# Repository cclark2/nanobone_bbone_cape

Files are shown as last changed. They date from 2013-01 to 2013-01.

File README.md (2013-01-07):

NanoBone BeagleBone Cape
========================

A cape connecting all BeagleBone P8/P9 I/Os to the pins of the $89 DE0-Nano FPGA board. Use it to add an FPGA to your BeagleBone project!

Special thanks to <a href="http://www.sparkfun.com/">SparkFun</a> for use of their open-source EAGLE libraries.

## Project Links
- <a href="http://www.hitchhikeree.org/beaglebone_capes/nanobone/">HitchhikerEE page</a>
- <a href="http://www.youtube.com/watch?v=jys_sxTUOd8">YouTube video</a>
- <a href="https://docs.google.com/folder/d/0B5HjtPsFD8u5YW9CNGdPOElQOEU/edit">Design files on Google Drive</a>
- <a href="http://beagleboard.org/CapeContest/entries/NanoBone/">BeagleBone Cape Contest page</a>

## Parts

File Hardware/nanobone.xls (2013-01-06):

Qty | Value | Device | Package | Parts | Description | MF | MPN | Price | Total
1 |  | CAT24C256 | SOIC8 | U$1 |  |  | CAT24C256WI-GT3 | $0.65 | $0.65
2 |  | FE20-2 | FE20-2 | SV1, SV2 | FEMALE HEADER |  | NPPC202KFMS-RC | 3.9 | 7.8
2 |  | FE23-2_SMD | FE23-2_SMD | P8, P9 | FEMALE HEADER |  | NPPC232KFMS-RC | 3.54 | 7.08
4 |  | HOLE | HOLE | H1, H2, H3, H4 |  |  |  |  | 0
1 |  | M02LOCK_LONGPADS | 1X02_LOCK_LONGPADS | JP1 | Header 2 |  |  |  | 0
1 |  | MA03-1 | MA03-1 | SV3 | PIN HEADER |  |  |  | 0
1 | 0.1u | C-EUC0603 | C0603 | C1 | CAPACITOR, European symbol |  | VJ0603V104ZXXCW1BC | 0.06 | 0.06
1 | 10K | R-US_R0603 | R0603 | R9 | RESISTOR, American symbol |  | WR06X1002FTL | 0.02 | 0.02
1 | 150 | R-US_R0603 | R0603 | R6 | RESISTOR, American symbol |  | 302-150-RC | 0.04 | 0.04
1 | 219-02 | 219-02 | CTS-219-02 | S1 | Surface Mount DIP Switch Series 219 SMT |  | 219-2MST | 0.58 | 0.58
3 | 4.75K | R-US_R0603 | R0603 | R2, R5, R7 | RESISTOR, American symbol |  | CR0603-FX-4751GLF | 0.04 | 0.12
1 | 4.75K, DNI | R-US_R0603 | R0603 | R4 | RESISTOR, American symbol |  | CR0603-FX-4751GLF | 0.04 | 0.04
2 | 5.6K, 5% | R-US_R0603 | R0603 | R1, R3 | RESISTOR, American symbol |  | RK73B1JTTDD562J | 0.06 | 0.12
1 | 50 | R-US_R0603 | R0603 | R8 | RESISTOR, American symbol |  | 302-49.9-RC | 0.04 | 0.04
1 | TPB2,54 | TPB2,54 | B2,54 | TP1 | Test pad |  |  |  | 0
1 | blue | LEDCHIPLED_0603 | CHIPLED_0603 | LED1 | LED |  | HT-193NB-5589 | 0.15 | 0.15
1 | green | LEDCHIPLED_0603 | CHIPLED_0603 | LED2 | LED |  | LG Q971-KN-1 | 0.1 | 0.1
 |  |  |  |  |  |  |  |  | $16.80
 |  |  |  |  |  |  | Need an $86.25 DE0-Nano board from DigiKey
 |  |  |  |  |  |  | Need male headers to mate cape to BeagleBone

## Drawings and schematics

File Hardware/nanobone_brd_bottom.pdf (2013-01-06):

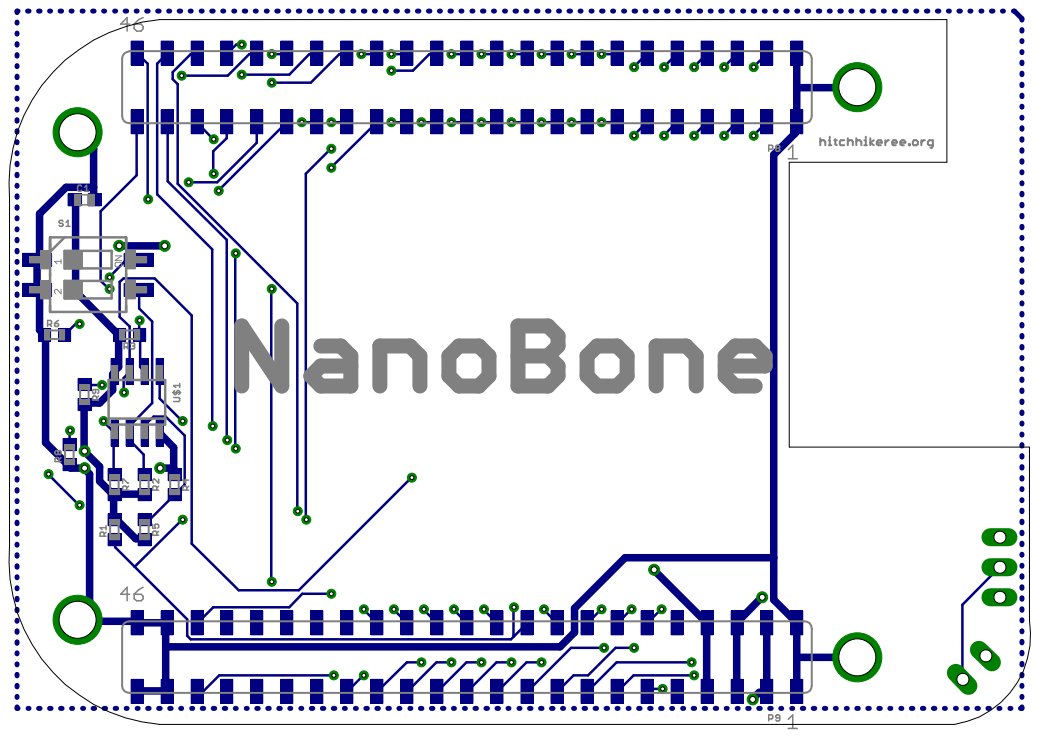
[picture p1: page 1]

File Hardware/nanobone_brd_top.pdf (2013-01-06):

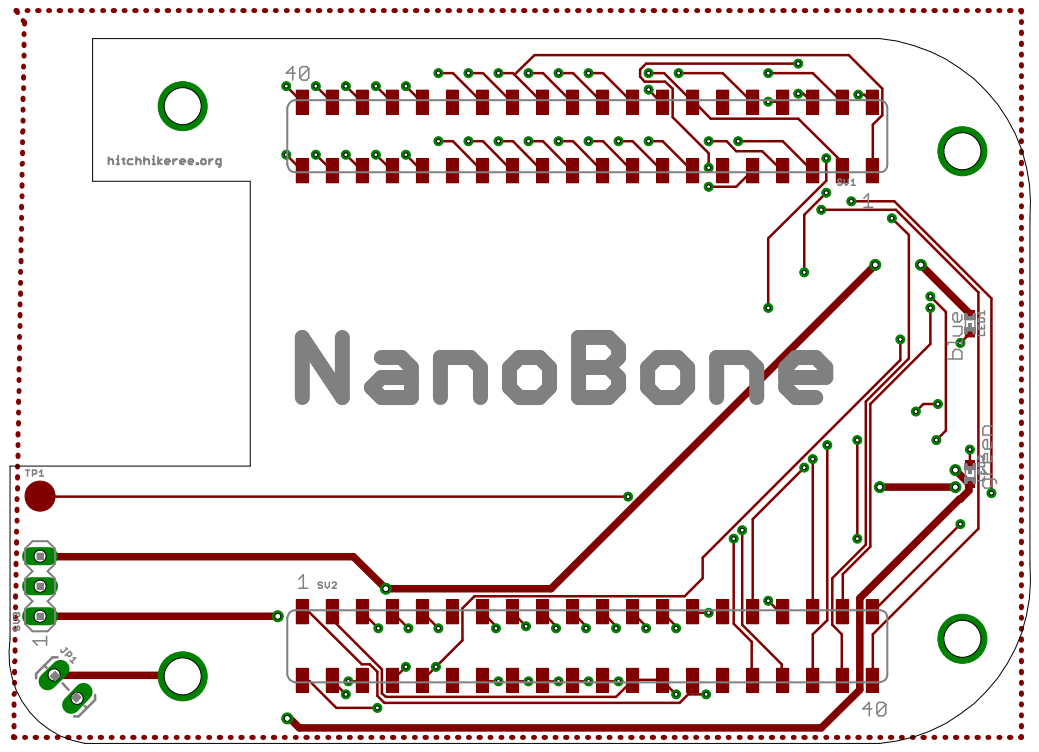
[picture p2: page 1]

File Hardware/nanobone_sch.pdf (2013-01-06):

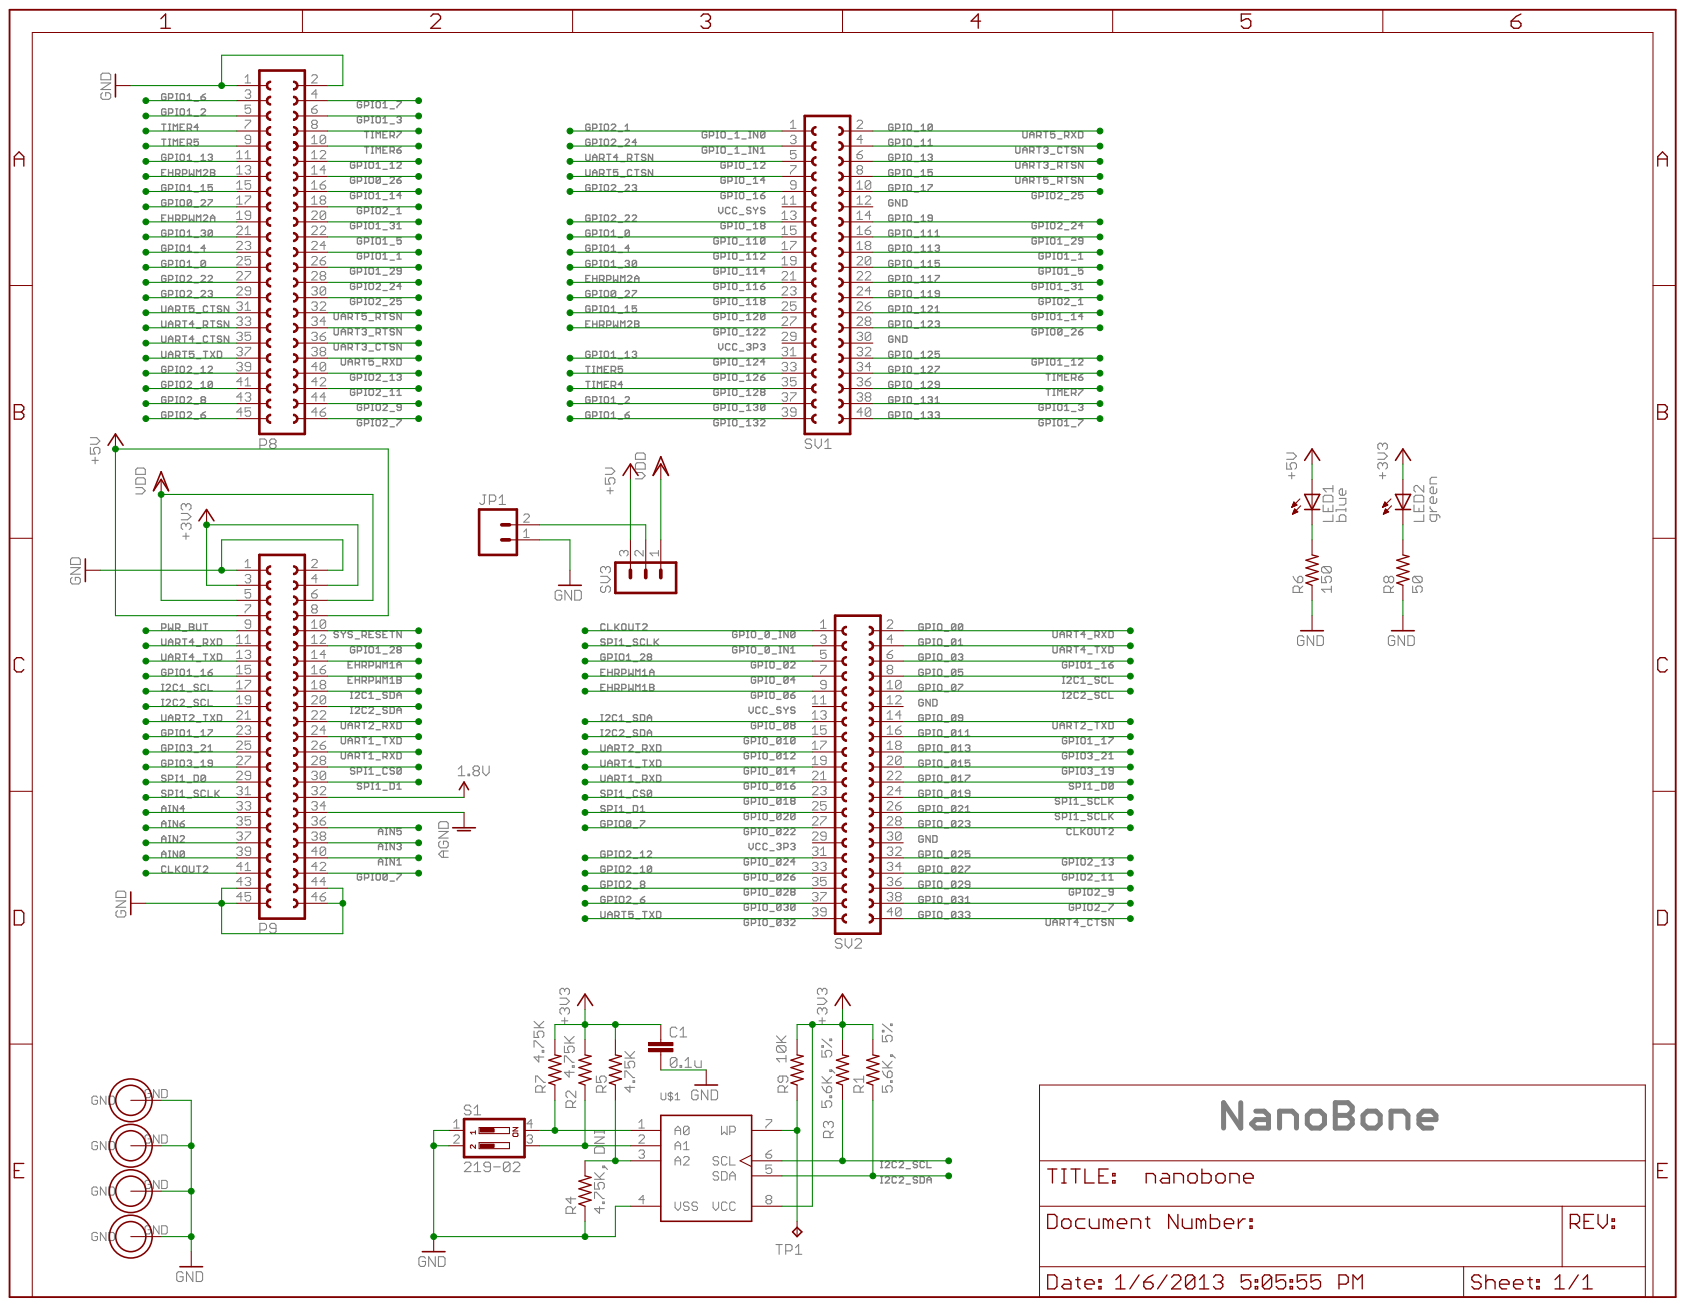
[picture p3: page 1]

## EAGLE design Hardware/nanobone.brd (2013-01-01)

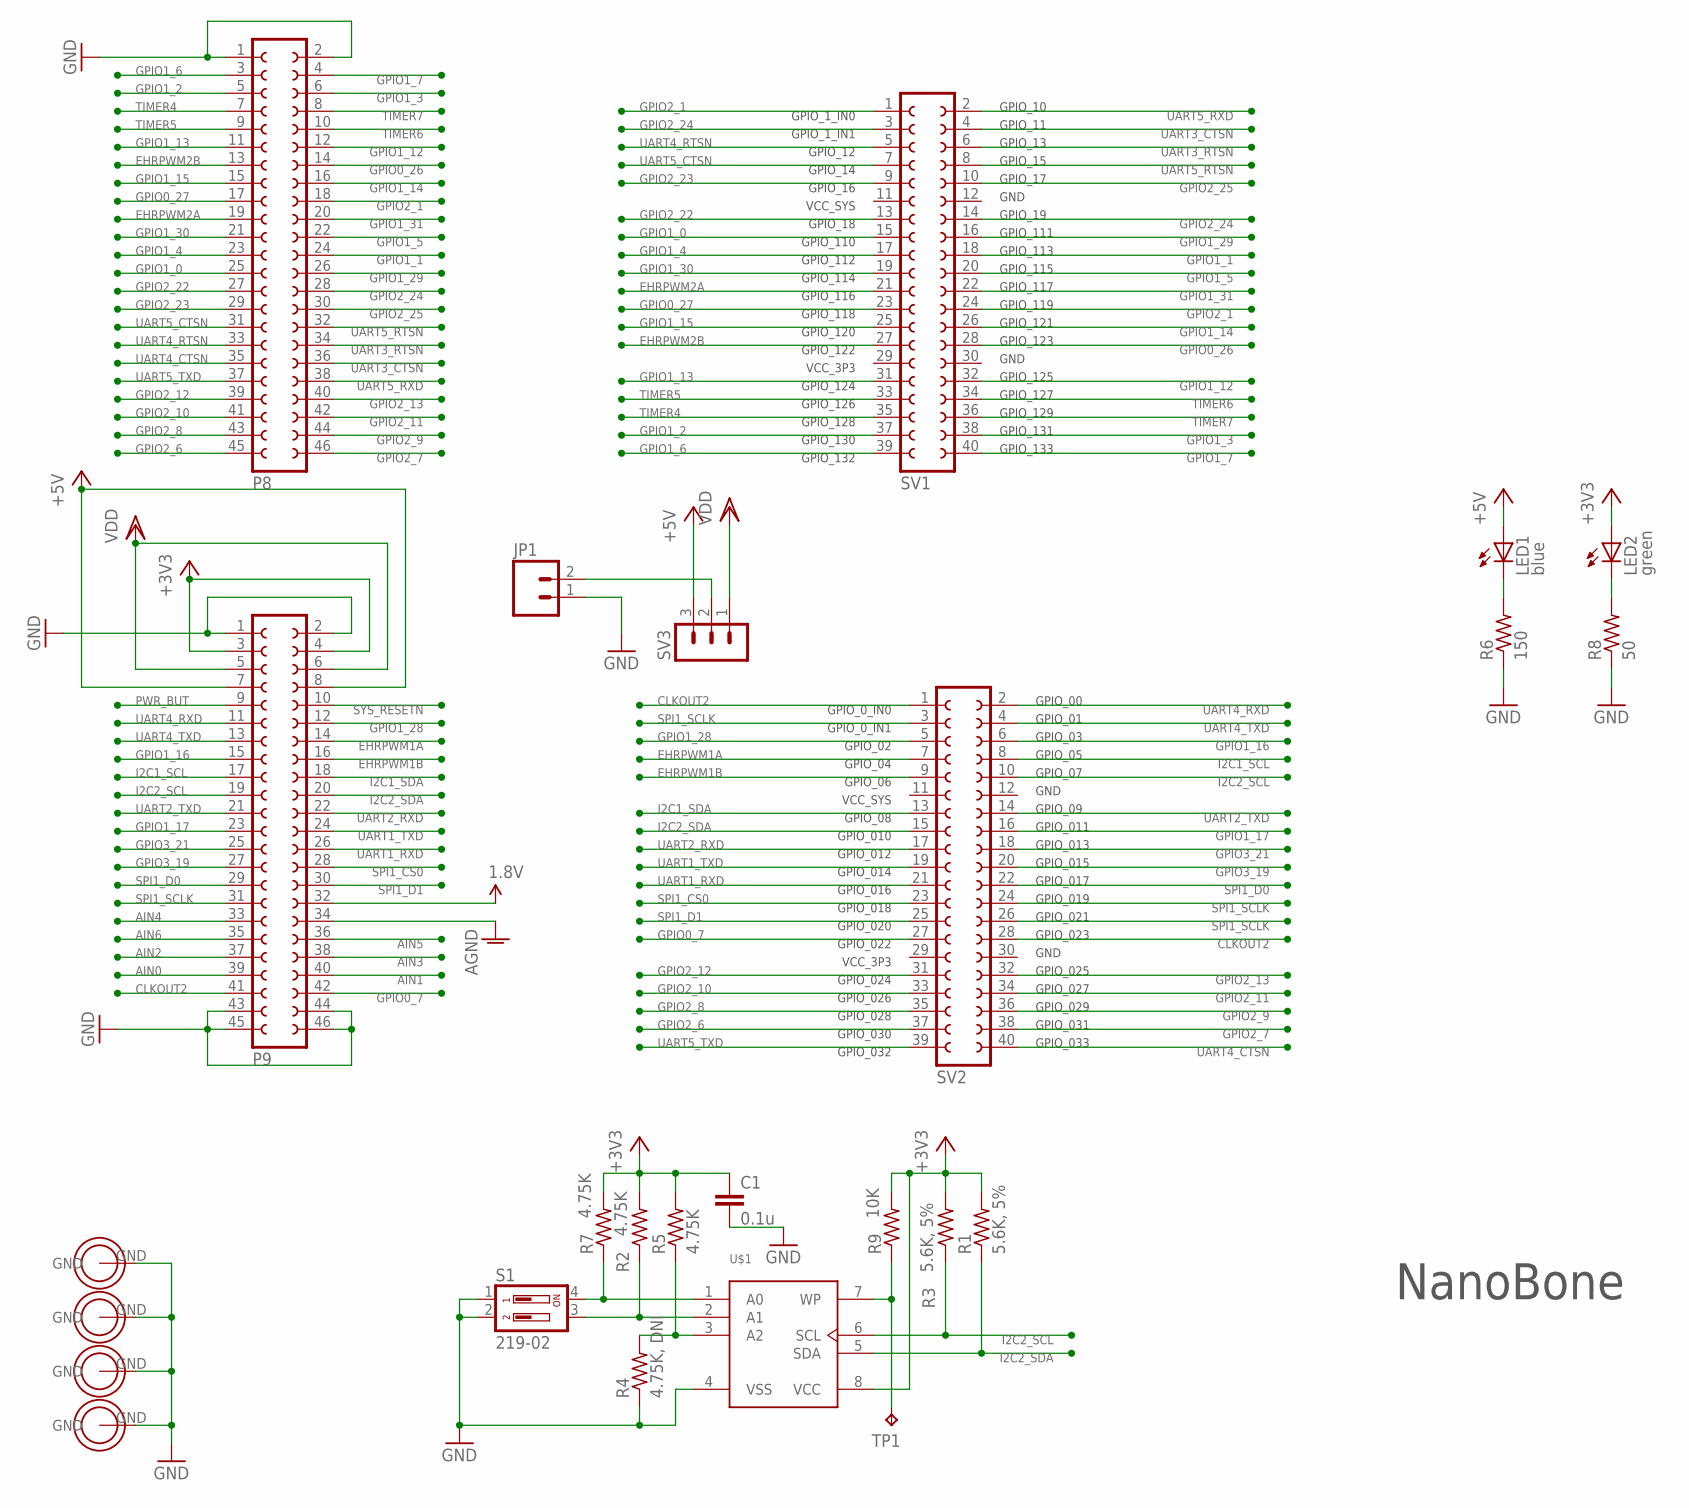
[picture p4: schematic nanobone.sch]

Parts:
C1: 0.1u; C0603; MPN VJ0603V104ZXXCW1BC
H1, H2, H3, H4: HOLE
JP1: M02LOCK_LONGPADS; 1X02_LOCK_LONGPADS
LED1: blue; CHIPLED_0603; MPN HT-193NB-5589
LED2: green; CHIPLED_0603; MPN LG Q971-KN-1
P8, P9: FE23-2_SMD; MPN NPPC232KFMS-RC
R1, R3: 5.6K, 5%; R0603; MPN RK73B1JTTDD562J
R2, R5, R7: 4.75K; R0603; MPN CR0603-FX-4751GLF
R4: 4.75K, DNI; R0603; MPN CR0603-FX-4751GLF
R6: 150; R0603; MPN 302-150-RC
R8: 50; R0603; MPN 302-49.9-RC
R9: 10K; R0603; MPN WR06X1002FTL
S1: 219-02; CTS-219-02; MPN 219-2MST
SV1, SV2: FE20-2; MPN NPPC202KFMS-RC
SV3: MA03-1
TP1: TPB2,54; B2,54
U$1: CAT24C256; SOIC8; MPN CAT24C256WI-GT3

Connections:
1.8V: P9.32
+3V3: C1.1, LED2.A, P9.3, P9.4, R1.2, R2.2, R3.2, R5.2, R7.2, R9.2, U$1.8 (VCC)
+5V: LED1.A, P9.7, P9.8, SV3.3
AGND: P9.34
AIN0: P9.39
AIN1: P9.40
AIN2: P9.37
AIN3: P9.38
AIN4: P9.33
AIN5: P9.36
AIN6: P9.35
CLKOUT2: P9.41, SV2.1, SV2.28
EHRPWM1A: P9.14, SV2.7
EHRPWM1B: P9.16, SV2.9
EHRPWM2A: P8.19, SV1.21
EHRPWM2B: P8.13, SV1.27
GND: C1.2, H1.GND, H2.GND, H3.GND, H4.GND, JP1.1, P8.1, P8.2, P9.1, P9.2, P9.43, P9.44, P9.45, P9.46, R4.1, R6.1, R8.1, S1.1, S1.2, U$1.4 (VSS)
GPIO0_7: P9.42, SV2.27
GPIO0_26: P8.14, SV1.28
GPIO0_27: P8.17, SV1.23
GPIO1_0: P8.25, SV1.15
GPIO1_1: P8.24, SV1.18
GPIO1_2: P8.5, SV1.37
GPIO1_3: P8.6, SV1.38
GPIO1_4: P8.23, SV1.17
GPIO1_5: P8.22, SV1.20
GPIO1_6: P8.3, SV1.39
GPIO1_7: P8.4, SV1.40
GPIO1_12: P8.12, SV1.32
GPIO1_13: P8.11, SV1.31
GPIO1_14: P8.16, SV1.26
GPIO1_15: P8.15, SV1.25
GPIO1_16: P9.15, SV2.6
GPIO1_17: P9.23, SV2.16
GPIO1_28: P9.12, SV2.5
GPIO1_29: P8.26, SV1.16
GPIO1_30: P8.21, SV1.19
GPIO1_31: P8.20, SV1.22
GPIO2_1: P8.18, SV1.1, SV1.24
GPIO2_6: P8.45, SV2.37
GPIO2_7: P8.46, SV2.38
GPIO2_8: P8.43, SV2.35
GPIO2_9: P8.44, SV2.36
GPIO2_10: P8.41, SV2.33
GPIO2_11: P8.42, SV2.34
GPIO2_12: P8.39, SV2.31
GPIO2_13: P8.40, SV2.32
GPIO2_22: P8.27, SV1.13
GPIO2_23: P8.29, SV1.9
GPIO2_24: P8.28, SV1.3, SV1.14
GPIO2_25: P8.30, SV1.10
GPIO3_19: P9.27, SV2.20
GPIO3_21: P9.25, SV2.18
I2C1_SCL: P9.17, SV2.8
I2C1_SDA: P9.18, SV2.13
I2C2_SCL: P9.19, R3.1, SV2.10, U$1.6 (SCL)
I2C2_SDA: P9.20, R1.1, SV2.15, U$1.5 (SDA)
unnamed: R7.1, S1.4, U$1.1 (A0)
unnamed: R2.1, S1.3, U$1.2 (A1)
unnamed: R4.2, R5.1, U$1.3 (A2)
unnamed: JP1.2, SV3.2
unnamed: R9.1, TP1.TP, U$1.7 (WP)
unnamed: LED1.C, R6.2
unnamed: LED2.C, R8.2
PWR_BUT: P9.9
SPI1_CS0: P9.28, SV2.23
SPI1_D0: P9.29, SV2.22
SPI1_D1: P9.30, SV2.25
SPI1_SCLK: P9.31, SV2.3, SV2.24, SV2.26
SYS_RESETN: P9.10
TIMER4: P8.7, SV1.35
TIMER5: P8.9, SV1.33
TIMER6: P8.10, SV1.34
TIMER7: P8.8, SV1.36
UART1_RXD: P9.26, SV2.21
UART1_TXD: P9.24, SV2.19
UART2_RXD: P9.22, SV2.17
UART2_TXD: P9.21, SV2.14
UART3_CTSN: P8.36, SV1.4
UART3_RTSN: P8.34, SV1.6
UART4_CTSN: P8.35, SV2.40
UART4_RTSN: P8.33, SV1.5
UART4_RXD: P9.11, SV2.2
UART4_TXD: P9.13, SV2.4
UART5_CTSN: P8.31, SV1.7
UART5_RTSN: P8.32, SV1.8
UART5_RXD: P8.38, SV1.2
UART5_TXD: P8.37, SV2.39
VDD: P9.5, P9.6, SV3.1

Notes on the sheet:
NanoBone
GPIO_0_IN0
GPIO_00
GPIO_01
GPIO_03
GPIO_05
GPIO_07
GND
GPIO_09
GPIO_011
GPIO_013
GPIO_015
GPIO_017
GPIO_019
GPIO_021
GPIO_023
GPIO_025
GPIO_027
GPIO_029
GPIO_031
GPIO_033
GPIO_10
GPIO_11
GPIO_13
GPIO_15
GPIO_17
GPIO_19
GPIO_111
GPIO_113
GPIO_115
GPIO_117
GPIO_119
GPIO_121
GPIO_123
GPIO_125
GPIO_127
GPIO_129
GPIO_131
GPIO_133
GPIO_1_IN0

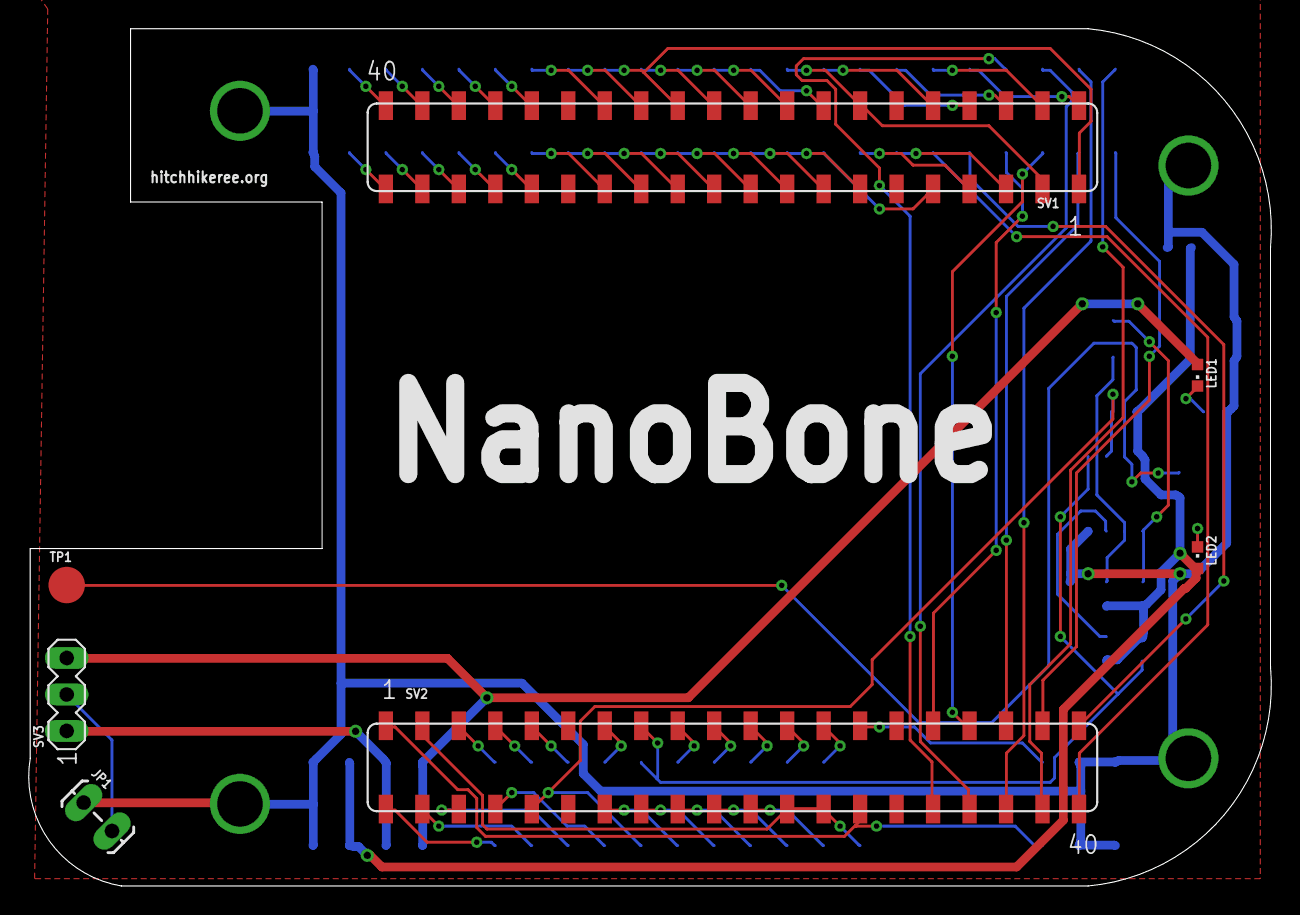
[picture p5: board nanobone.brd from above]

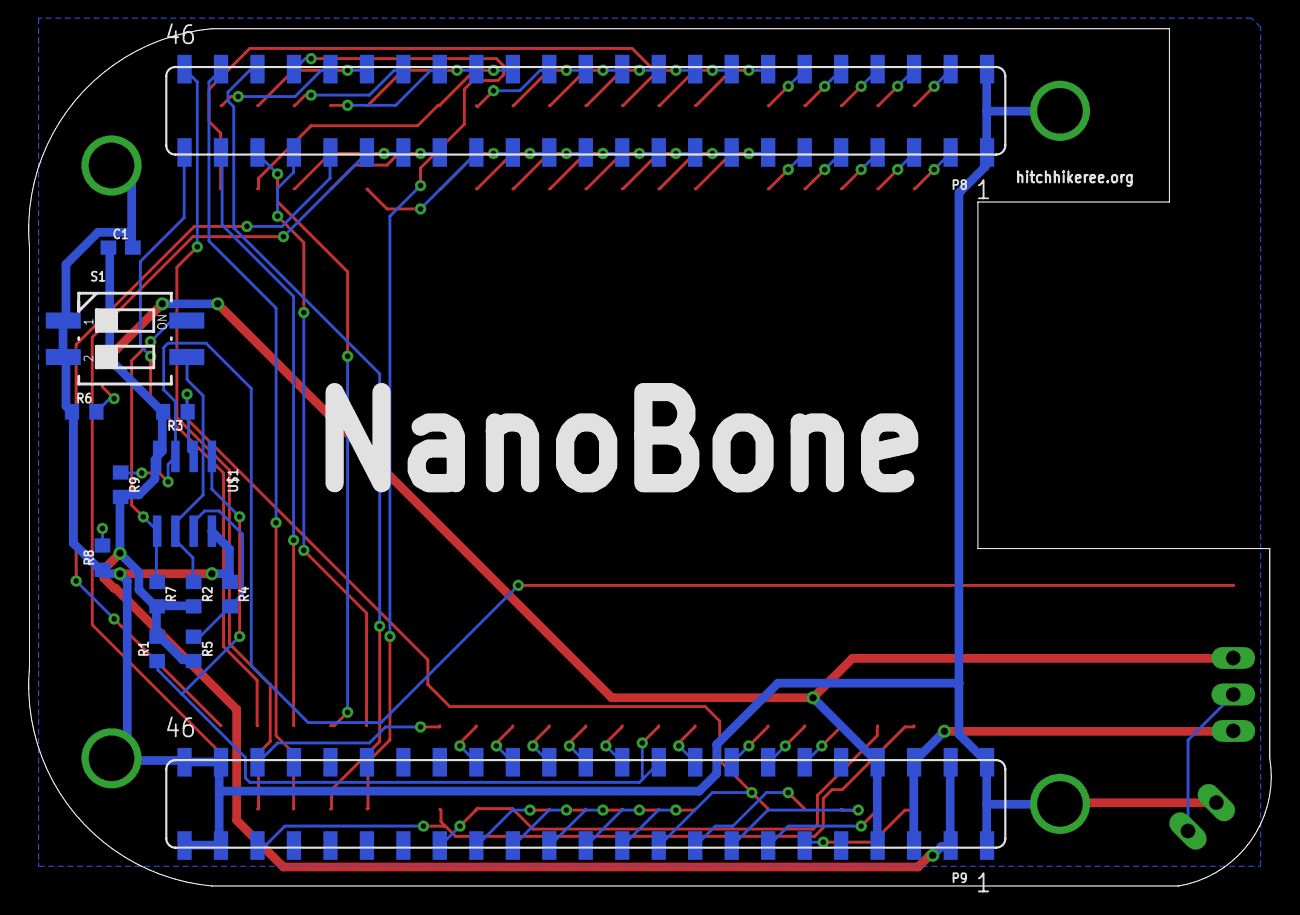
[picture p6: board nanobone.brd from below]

Board: 2 copper layers, 86.5 x 59.7 mm, 25 parts (14 on the bottom side), 78 nets.

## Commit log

2013-01-01 Design complete, cleanup needed.
    [nanobone.brd, nanobone.sch, nanobone.xlsx]
2013-01-01 BOM done.
    [nanobone.brd, nanobone.sch, nanobone.xls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]
2013-01-06 Added BOM prices, added PDFs of design, sorted files.
    [nanobone.brd, nanobone.sch, nanobone.xls]

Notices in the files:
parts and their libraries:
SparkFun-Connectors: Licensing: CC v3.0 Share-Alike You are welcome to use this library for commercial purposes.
